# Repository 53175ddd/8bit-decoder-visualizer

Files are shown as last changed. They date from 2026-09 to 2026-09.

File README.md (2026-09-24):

# 8bit-decoder-visualizer

基板イメージ



動作イメージ（YouTube に飛びます）

youtube (https://www.youtube.com/watch?v=ziqk_MC2Dsg)

## 部品表

| 部品番号 | 部品名 | 個数 | リンク |
|:----|:----|----:|:----|
| C1 | 0.1uF 1608M | 1 | [113374](<https://akizukidenshi.com/catalog/g/g113374/>) |
| D1 ~ D8 | LED 5mm | 8 | [112605](<https://akizukidenshi.com/catalog/g/g112605/>) |
| D9 ~ D16 | 1N4148W SOD-123F | 8 | [g116985](<https://akizukidenshi.com/catalog/g/g116985/>) |
| R1 ~ R8 | 1kΩ 1608M | 8 | [130351](<https://akizukidenshi.com/catalog/g/g130351/>) |
| R9 ~ R12 | 10kΩ 1608M | 4 | [130355](<https://akizukidenshi.com/catalog/g/g130355/>) |
| SW1 ~ SW8 | SPDT トグルスイッチ | 8 | [100300](<https://akizukidenshi.com/catalog/g/g100300/>) |
| U1 ~ U6 | 7 セグメント LED モジュール | 6 | [110360](<https://akizukidenshi.com/catalog/g/g110360/>) |
| U7 | 74HC595 | 1 | [131760](<https://akizukidenshi.com/catalog/g/g131760/>) |
| U8 | Seeed XIAO | 1 | [117044](<https://akizukidenshi.com/catalog/g/g117044/>) |

---

<a href="https://github.com/53175ddd/8bit-decoder-visualizer">This work</a> is licensed under <a href="https://creativecommons.org/licenses/by-sa/4.0/">CC BY-SA 4.0</a></br>


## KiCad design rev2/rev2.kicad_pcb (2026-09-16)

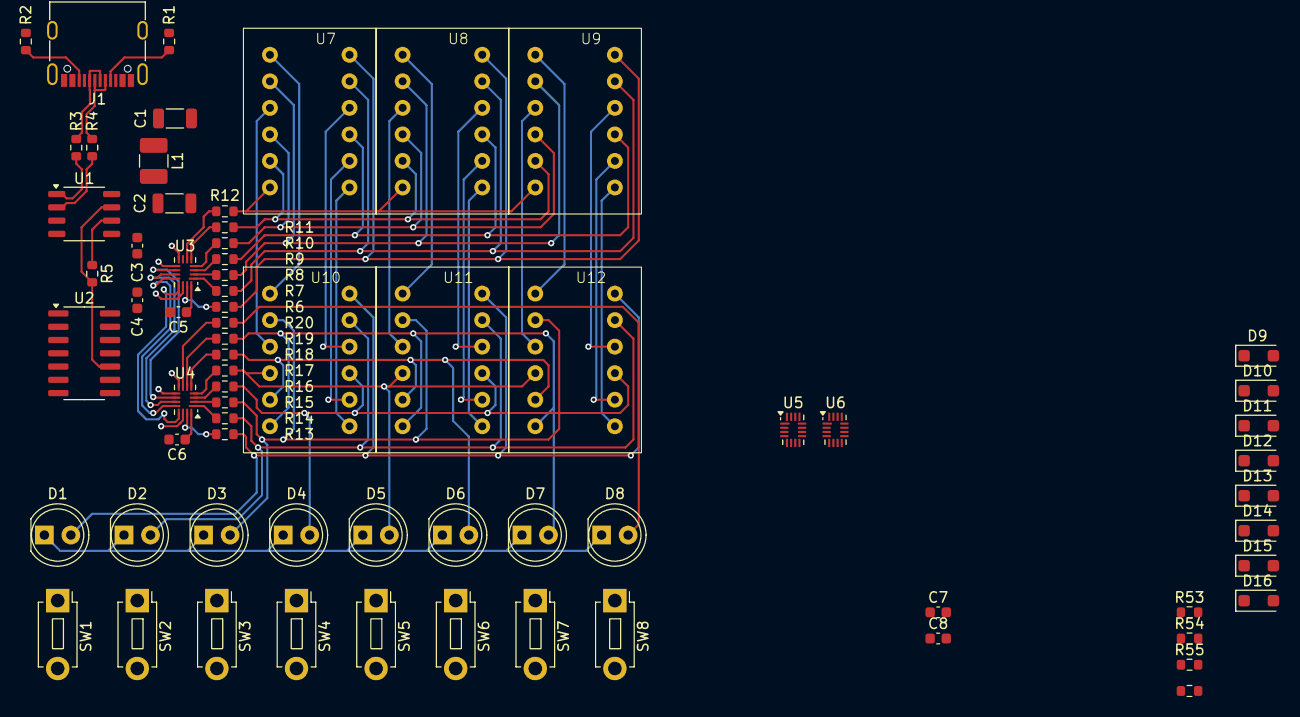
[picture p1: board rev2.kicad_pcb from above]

Board: 2 copper layers, 70 parts (0 on the bottom side), 78 nets.

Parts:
C1, C2: 10uF; L_1206_3216Metric
C3, C4, C5, C6, C7, C8: 0.1uF; C_0603_1608Metric
D1, D2, D3, D4, D5, D6, D7, D8: LED; LED_D5.0mm
D9, D10, D11, D12, D13, D14, D15, D16: D; D_SOD-123F
J1: USB_C_Receptacle_USB2.0_14P; USB_C_Receptacle_G-Switch_GT-USB-7010ASV
L1: 1.5uH; L_1210_3225Metric_Pad1.42x2.65mm_HandSolder
R1, R2: 5.1k; R_0603_1608Metric
R3, R4: 22; R_0603_1608Metric
R5, R6, R7, R8, R9, R10, R11, R12, R13, R14, R15, R16, R17, R18, R19, R20: 1k; R_0603_1608Metric
R53, R54, R55, R56: 10k; R_0603_1608Metric
SW1, SW2, SW3, SW4, SW5, SW6, SW7, SW8: SW_Push; SW_PUSH_1P1T_6x3.5mm_H4.3_APEM_MJTP1243
U1: CH340N; SOP-8_3.9x4.9mm_P1.27mm
U2: ATtiny1604-SS; SOIC-14_3.9x8.7mm_P1.27mm
U3, U4, U5, U6: 74HC595; UQFN-16_1.8x2.6mm_P0.4mm
U7, U8, U9, U10, U11, U12: C-2570SR

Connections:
+5V: C2.1, C3.1, C4.1, C5.1, C6.1, C7.1, C8.1, L1.2, R53.1, R54.1, R55.1, R56.1, U1.5 (VCC), U2.1 (VCC), U3.16 (VCC), U4.16 (VCC), U5.16 (VCC), U6.16 (VCC)
/DN: R4.2, U1.2 (UD-)
/DP: R3.2, U1.1 (UD+)
/HC595_CLEAR: U3.10 (~SRCLR), U4.10 (~SRCLR), U5.10 (~SRCLR), U6.10 (~SRCLR)
/HC595_CLOCK: U3.11 (SRCLK), U4.11 (SRCLK), U5.11 (SRCLK), U6.11 (SRCLK)
/HC595_EN: U3.13 (~OE), U4.13 (~OE), U5.13 (~OE), U6.13 (~OE)
/HC595_LATCH: U3.12 (RCLK), U4.12 (RCLK), U5.12 (RCLK), U6.12 (RCLK)
/READ_0: R53.2, SW1.2, SW5.2
/READ_1: R54.2, SW2.2, SW6.2
/READ_2: R55.2, SW3.2, SW7.2
/READ_3: R56.2, SW4.2, SW8.2
/SCAN_0: D9.1 (K), D10.1 (K), D11.1 (K), D12.1 (K)
/SCAN_1: D13.1 (K), D14.1 (K), D15.1 (K), D16.1 (K)
/SOURCE_1A: R6.2, U7.12 (ROW1), U8.12 (ROW1), U9.12 (ROW1)
/SOURCE_1B: R7.2, U7.11 (ROW2), U8.11 (ROW2), U9.11 (ROW2)
/SOURCE_1C: R8.2, U7.2 (ROW3), U8.2 (ROW3), U9.2 (ROW3)
/SOURCE_1D: R9.2, U7.9 (ROW4), U8.9 (ROW4), U9.9 (ROW4)
/SOURCE_1E: R10.2, U7.4 (ROW5), U8.4 (ROW5), U9.4 (ROW5)
/SOURCE_1F: R11.2, U7.5 (ROW6), U8.5 (ROW6), U9.5 (ROW6)
/SOURCE_1G: R12.2, U7.6 (ROW7), U8.6 (ROW7), U9.6 (ROW7)
/SOURCE_2A: D1.2 (A), R13.2, U10.12 (ROW1), U11.12 (ROW1), U12.12 (ROW1)
/SOURCE_2B: D2.2 (A), R14.2, U10.11 (ROW2), U11.11 (ROW2), U12.11 (ROW2)
/SOURCE_2C: D3.2 (A), R15.2, U10.2 (ROW3), U11.2 (ROW3), U12.2 (ROW3)
/SOURCE_2D: D4.2 (A), R16.2, U10.9 (ROW4), U11.9 (ROW4), U12.9 (ROW4)
/SOURCE_2E: D5.2 (A), R17.2, U10.4 (ROW5), U11.4 (ROW5), U12.4 (ROW5)
/SOURCE_2F: D6.2 (A), R18.2, U10.5 (ROW6), U11.5 (ROW6), U12.5 (ROW6)
/SOURCE_2G: D7.2 (A), R19.2, U10.6 (ROW7), U11.6 (ROW7), U12.6 (ROW7)
/SOURCE_2H: D8.2 (A), R20.2
/UPDI: R5.2, U1.7 (RXD), U2.10 (~RESET/PA0)
/USB_PLUG_DN: J1.A7 (D-), J1.B7 (D-), R4.1
/USB_PLUG_DP: J1.A6 (D+), J1.B6 (D+), R3.1
GND: C1.2, C2.2, C3.2, C4.2, C5.2, C6.2, C7.2, C8.2, J1.A1 (GND), J1.A12 (GND), J1.B1 (GND), J1.B12 (GND), J1.S1 (SHIELD), R1.2, R2.2, U1.3 (GND), U2.14 (GND), U3.8 (GND), U4.8 (GND), U5.8 (GND), U6.8 (GND)
unnamed: D1.1 (K), D2.1 (K), D3.1 (K), D4.1 (K), D5.1 (K), D6.1 (K), D7.1 (K), D8.1 (K)
unnamed: D9.2 (A), SW1.1
unnamed: D10.2 (A), SW2.1
unnamed: D11.2 (A), SW3.1
unnamed: D12.2 (A), SW4.1
unnamed: D13.2 (A), SW5.1
unnamed: D14.2 (A), SW6.1
unnamed: D15.2 (A), SW7.1
unnamed: D16.2 (A), SW8.1
unnamed: J1.A5 (CC1), R1.1
unnamed: J1.B5 (CC2), R2.1
unnamed: U7.1 (COL1), U10.1 (COL1)
unnamed: U7.3 (COL2), U10.3 (COL2)
unnamed: U7.10 (COL3), U10.10 (COL3)
unnamed: U7.7 (COL4), U10.7 (COL4)
unnamed: U7.8 (COL5), U10.8 (COL5)
unnamed: U8.1 (COL1), U11.1 (COL1)
unnamed: U8.3 (COL2), U11.3 (COL2)
unnamed: U8.10 (COL3), U11.10 (COL3)
unnamed: U8.7 (COL4), U11.7 (COL4)
unnamed: U8.8 (COL5), U11.8 (COL5)
unnamed: U9.1 (COL1), U12.1 (COL1)
unnamed: U9.3 (COL2), U12.3 (COL2)
unnamed: U9.10 (COL3), U12.10 (COL3)
unnamed: U9.7 (COL4), U12.7 (COL4)
unnamed: U9.8 (COL5), U12.8 (COL5)
unnamed: R5.1, U1.6 (TXD)
unnamed: R6.1, U3.15 (QA)
unnamed: R7.1, U3.1 (QB)
unnamed: R8.1, U3.2 (QC)
unnamed: R9.1, U3.3 (QD)
unnamed: R10.1, U3.4 (QE)
unnamed: R11.1, U3.5 (QF)
unnamed: R12.1, U3.6 (QG)
unnamed: U3.9 (QH'), U4.14 (SER)
unnamed: R13.1, U4.15 (QA)
unnamed: R14.1, U4.1 (QB)
unnamed: R15.1, U4.2 (QC)
unnamed: R16.1, U4.3 (QD)
unnamed: R17.1, U4.4 (QE)
unnamed: R18.1, U4.5 (QF)
unnamed: R19.1, U4.6 (QG)
unnamed: U4.9 (QH'), U5.14 (SER)
unnamed: R20.1, U4.7 (QH)
unnamed: U5.9 (QH'), U6.14 (SER)
VBUS: C1.1, J1.A4 (VBUS), J1.A9 (VBUS), J1.B4 (VBUS), J1.B9 (VBUS), L1.1

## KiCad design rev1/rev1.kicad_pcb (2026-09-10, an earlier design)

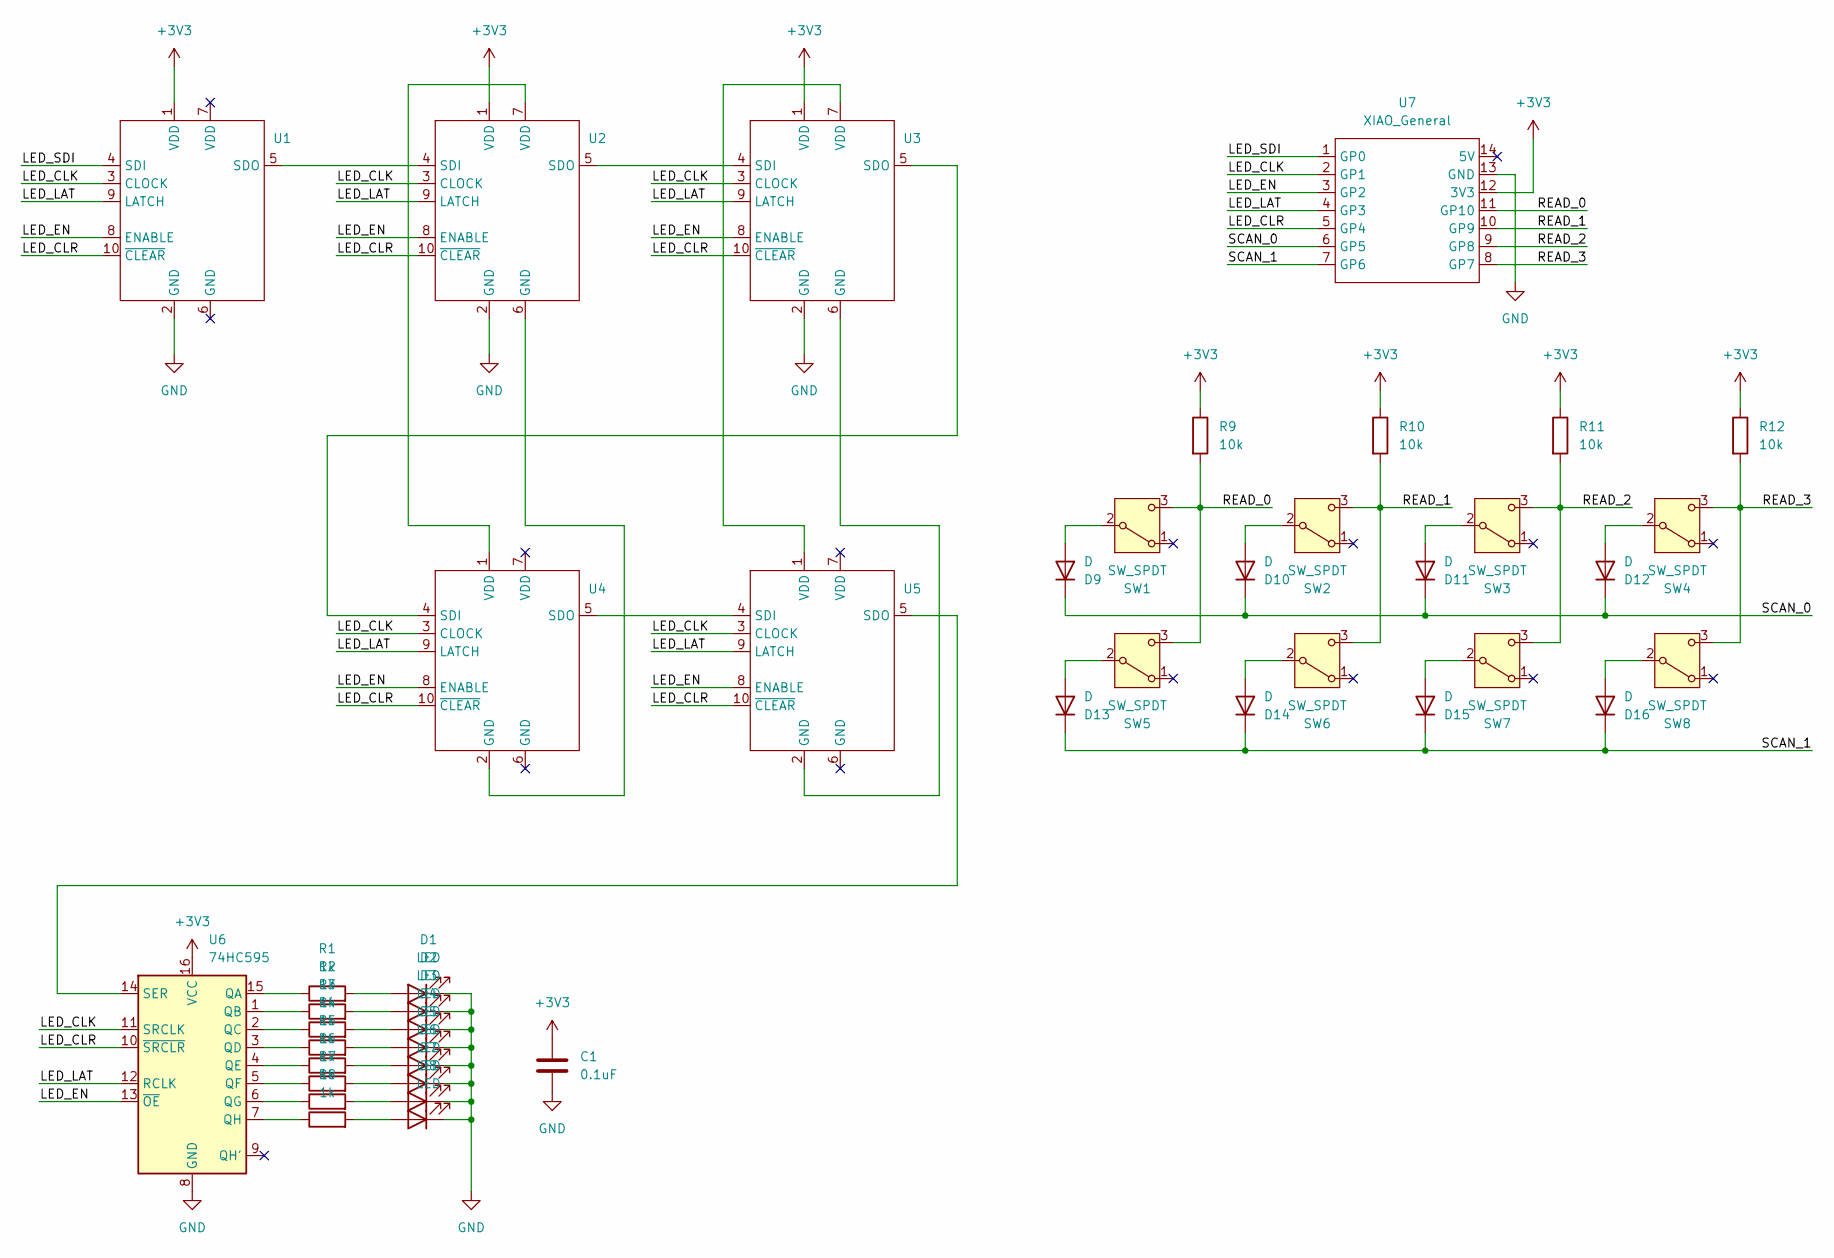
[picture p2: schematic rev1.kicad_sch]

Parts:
C1: 0.1uF; C_0603_1608Metric
D1, D2, D3, D4, D5, D6, D7, D8: LED; LED_D5.0mm
D9, D10, D11, D12, D13, D14, D15, D16: D; D_SOD-123F
R1, R2, R3, R4, R5, R6, R7, R8: 1k; R_0603_1608Metric
R9, R10, R11, R12: 10k; R_0603_1608Metric
SW1, SW2, SW3, SW4, SW5, SW6, SW7, SW8: SW_SPDT; SW_SPDT_100300
U1, U2, U3, U4, U5: LED Display Module; LED_Display_Module
U6: 74HC595; DIP-16_W7.62mm
U7: XIAO_General; XIAO_ESP32_C3

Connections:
+3V3: C1.1, R9.1, R10.1, R11.1, R12.1, U1.1 (VDD), U2.1 (VDD), U3.1 (VDD), U6.16 (VCC), U7.12 (3V3)
/LED_CLK: U1.3 (CLOCK), U2.3 (CLOCK), U3.3 (CLOCK), U4.3 (CLOCK), U5.3 (CLOCK), U6.11 (SRCLK), U7.2 (GP1)
/LED_CLR: U1.10 (~CLEAR), U2.10 (~CLEAR), U3.10 (~CLEAR), U4.10 (~CLEAR), U5.10 (~CLEAR), U6.10 (~SRCLR), U7.5 (GP4)
/LED_EN: U1.8 (ENABLE), U2.8 (ENABLE), U3.8 (ENABLE), U4.8 (ENABLE), U5.8 (ENABLE), U6.13 (~OE), U7.3 (GP2)
/LED_LAT: U1.9 (LATCH), U2.9 (LATCH), U3.9 (LATCH), U4.9 (LATCH), U5.9 (LATCH), U6.12 (RCLK), U7.4 (GP3)
/LED_SDI: U1.4 (SDI), U7.1 (GP0)
/READ_0: R9.2, SW1.3 (C), SW5.3 (C), U7.11 (GP10)
/READ_1: R10.2, SW2.3 (C), SW6.3 (C), U7.10 (GP9)
/READ_2: R11.2, SW3.3 (C), SW7.3 (C), U7.9 (GP8)
/READ_3: R12.2, SW4.3 (C), SW8.3 (C), U7.8 (GP7)
/SCAN_0: D9.1 (K), D10.1 (K), D11.1 (K), D12.1 (K), U7.6 (GP5)
/SCAN_1: D13.1 (K), D14.1 (K), D15.1 (K), D16.1 (K), U7.7 (GP6)
GND: C1.2, D1.1 (K), D2.1 (K), D3.1 (K), D4.1 (K), D5.1 (K), D6.1 (K), D7.1 (K), D8.1 (K), U1.2 (GND), U2.2 (GND), U3.2 (GND), U6.8 (GND), U7.13 (GND)
unnamed: D1.2 (A), R1.2
unnamed: D2.2 (A), R2.2
unnamed: D3.2 (A), R3.2
unnamed: D4.2 (A), R4.2
unnamed: D5.2 (A), R5.2
unnamed: D6.2 (A), R6.2
unnamed: D7.2 (A), R7.2
unnamed: D8.2 (A), R8.2
unnamed: D9.2 (A), SW1.2 (B)
unnamed: D10.2 (A), SW2.2 (B)
unnamed: D11.2 (A), SW3.2 (B)
unnamed: D12.2 (A), SW4.2 (B)
unnamed: D13.2 (A), SW5.2 (B)
unnamed: D14.2 (A), SW6.2 (B)
unnamed: D15.2 (A), SW7.2 (B)
unnamed: D16.2 (A), SW8.2 (B)
unnamed: U1.5 (SDO), U2.4 (SDI)
unnamed: U2.6 (GND), U4.2 (GND)
unnamed: U2.5 (SDO), U3.4 (SDI)
unnamed: U2.7 (VDD), U4.1 (VDD)
unnamed: U3.6 (GND), U5.2 (GND)
unnamed: U3.5 (SDO), U4.4 (SDI)
unnamed: U3.7 (VDD), U5.1 (VDD)
unnamed: U4.5 (SDO), U5.4 (SDI)
unnamed: U5.5 (SDO), U6.14 (SER)
unnamed: R1.1, U6.15 (QA)
unnamed: R2.1, U6.1 (QB)
unnamed: R3.1, U6.2 (QC)
unnamed: R4.1, U6.3 (QD)
unnamed: R5.1, U6.4 (QE)
unnamed: R6.1, U6.5 (QF)
unnamed: R7.1, U6.6 (QG)
unnamed: R8.1, U6.7 (QH)

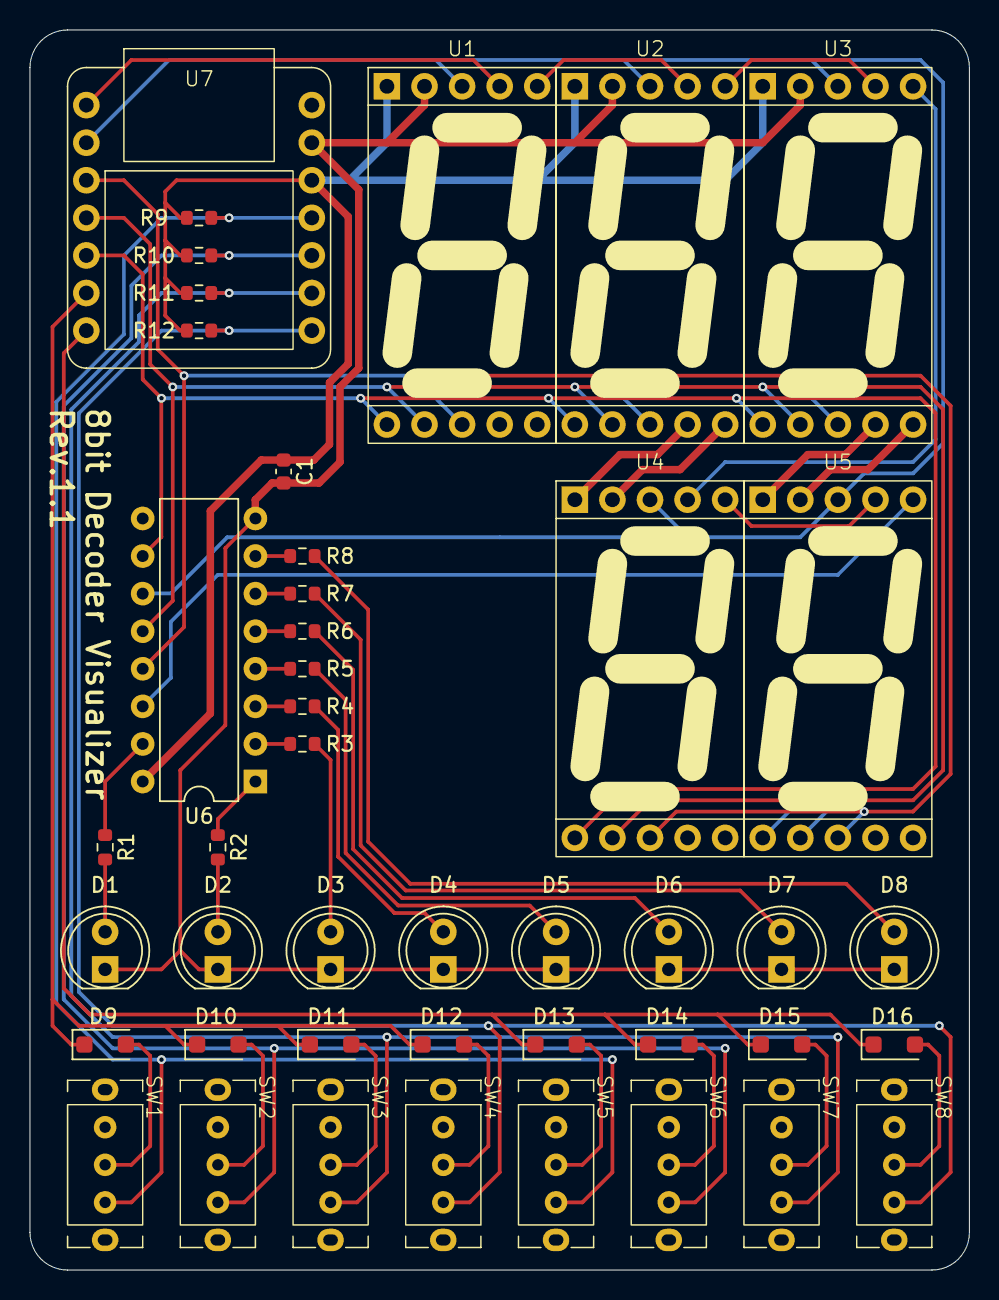
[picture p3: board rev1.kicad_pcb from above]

Board: 2 copper layers, 63.5 x 83.8 mm, 44 parts (0 on the bottom side), 46 nets.

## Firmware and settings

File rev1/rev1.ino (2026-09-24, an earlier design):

#define REV_1_1

#define LED_SDI  D0
#define LED_CLK  D1
#define LED_EN   D2
#define LED_LAT  D3
#define LED_CLR  D4
#define SCAN_0   D5
#define SCAN_1   D6
#define READ_0  D10
#define READ_1   D9
#define READ_2   D8
#define READ_3   D7

const uint8_t font[] = {0b11111100, 0b01100000, 0b11011010, 0b11110010, 0b01100110, 0b10110110, 0b10111110, 0b11100000, 0b11111110, 0b11110110, 0b11101110, 0b00111110, 0b00011010, 0b01111010, 0b10011110, 0b10001110};

const int8_t _scan[2] = {SCAN_0, SCAN_1};
const int8_t _read[4] = {READ_0, READ_1, READ_2, READ_3};


void init_io(void) {
  pinMode(LED_SDI, OUTPUT);
  pinMode(LED_CLK, OUTPUT);
  pinMode(LED_EN , OUTPUT);
  pinMode(LED_LAT, OUTPUT);
  pinMode(LED_CLR, OUTPUT);

  for(int8_t s = 0; s < 2; s++) {
    pinMode(_scan[s], OUTPUT);
    digitalWrite(_scan[s], HIGH);
  }

  for(int8_t r = 0; r < 4; r++) {
    pinMode(_read[r],  INPUT);
  }
}

void clear595(void) {
  digitalWrite(LED_CLR,  LOW);
  digitalWrite(LED_CLR, HIGH);
}

void send595(const uint8_t dat) {
  for(int8_t i = 0; i < 8; i++) {
    digitalWrite(LED_SDI, (dat >> i) & 1);
    digitalWrite(LED_CLK, HIGH);
    digitalWrite(LED_CLK, LOW);
  }
  digitalWrite(LED_SDI, LOW);
}

void latch595(void) {
  digitalWrite(LED_LAT, HIGH);
  digitalWrite(LED_LAT,  LOW);
}

uint8_t read_switch(void) {
  uint8_t res = 0;

  for(int8_t s = 0; s < 2; s++) digitalWrite(_scan[s], HIGH);

  for(int8_t s = 0; s < 2; s++) {
    digitalWrite(scan[s],  LOW);
    delayMicroseconds(20);

    for(int8_t r = 0; r < 4; r++) {
      res = (res << 1) + (digitalRead(_read[r]) == HIGH ? 0 : 1);
    }

    digitalWrite(_scan[s], HIGH);
  }

  return res;
}

void display(int8_t n) {
  static int8_t prev = -1;

  if(prev == n) return;
  prev = n;

#ifdef REV_1
  uint8_t vram[7] = {0};

  vram[0] = n;

  vram[6] = vram[0] / 100;
  vram[5] = (vram[0] / 10) % 10;
  vram[4] = vram[0] % 10;
  vram[3] = 0;
  vram[2] = vram[0] >> 4;
  vram[1] = vram[0] & 0x0F;

  vram[6] = font[vram[6]];
  vram[5] = font[vram[5]];
  vram[4] = font[vram[4]];
  vram[2] = font[vram[2]];
  vram[1] = font[vram[1]];

  if(vram[6] == font[0]) {
    vram[6] = 0;
    if(vram[5] == font[0]) {
      vram[5] = 0;
    }
  }

  if(vram[2] == font[0]) {
    vram[2] = 0;
  }
#endif

#ifdef REV_1_1
  uint8_t vram[6] = {0};

  vram[0] = n;

  vram[5] = vram[0] / 100;
  vram[4] = (vram[0] / 10) % 10;
  vram[3] = vram[0] % 10;
  vram[2] = vram[0] >> 4;
  vram[1] = vram[0] & 0x0F;

  vram[5] = font[vram[5]];
  vram[4] = font[vram[4]];
  vram[3] = font[vram[3]];
  vram[2] = font[vram[2]];
  vram[1] = font[vram[1]];

  if(vram[5] == font[0]) {
    vram[5] = 0;
    if(vram[4] == font[0]) {
      vram[4] = 0;
    }
  }

  if(vram[2] == font[0]) {
    vram[2] = 0;
  }
#endif

  for(int8_t i = 0; i < sizeof(vram); i++) {
    send595(vram[i]);
  }
  latch595();
}

void setup() {
  init_io();
  clear595();
}

void loop() {
  uint8_t n = read_switch();
  display(n);

  delay(25);
}

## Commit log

2026-08-18 kicad pj
    [8bit-decoder-visualizer.kicad_pcb, 8bit-decoder-visualizer.kicad_sch]
2026-08-18 デフォルトフットプリント割り当て
2026-08-18 表示器部分の回路作成
    [8bit-decoder-visualizer.kicad_sch]
2026-08-18 xiao のシンボル
2026-08-18 xiao の fp
2026-08-18 xiao との接続以外の回路を書いた
    [8bit-decoder-visualizer.kicad_sch]
2026-08-18 フットプリントの割り当てを忘れてたでヤンス
    [8bit-decoder-visualizer.kicad_sch]
2026-08-18 sym fp リメイク
2026-08-18 大まかな配線引いた
    [8bit-decoder-visualizer.kicad_pcb]
2026-08-18 未確定の配線を割り当て
    [8bit-decoder-visualizer.kicad_sch]
2026-08-18 配線整理
    [8bit-decoder-visualizer.kicad_pcb]
2026-08-18 回路調整
    [8bit-decoder-visualizer.kicad_sch]
2026-08-18 fix AW
    [8bit-decoder-visualizer.kicad_pcb]
2026-08-18 基板外形と寸法線
    [8bit-decoder-visualizer.kicad_pcb]
2026-08-18 シルク追加
    [8bit-decoder-visualizer.kicad_pcb]
2026-08-18 配線手直し
    [8bit-decoder-visualizer.kicad_pcb]
2026-08-18 基板外形をラウンドに変更
    [8bit-decoder-visualizer.kicad_pcb]
2026-08-19 配置配線を調整して基板を小型化
    [8bit-decoder-visualizer.kicad_pcb]
2026-09-02 ガーバー出力
    [8bit-decoder-visualizer.kicad_pcb]
2026-09-02 部品表作った
    [8bit-decoder-visualizer.kicad_sch]
2026-09-10 あるべきフットプリント
2026-09-10 いらない LED を消してスイッチのフットプリントを修正し、Rev.2 とする
    [8bit-decoder-visualizer.kicad_pcb, 8bit-decoder-visualizer.kicad_sch]
2026-09-10 基板中央とページ中央に近いグリッドがズレているのが気になったので平行移動
    [8bit-decoder-visualizer.kicad_pcb]
2026-09-10 Rev.2 じゃなくて Rev.1.1 にした
    [8bit-decoder-visualizer.kicad_pcb]
2026-09-10 replace to sub dir
    [8bit-decoder-visualizer.kicad_pcb, 8bit-decoder-visualizer.kicad_sch]
2026-09-10 create new version
    [rev2.kicad_pcb, rev2.kicad_sch]
2026-09-10 LED のシンボル作った
2026-09-10 LED のフットプリント
2026-09-11 だいたいの回路図書いた
    [rev2.kicad_sch]
2026-09-11 直前に表示した値と同じ値が渡されたら表示の更新をスキップするようにした
2026-09-13 ドットマトリックスを追加してダイナミック点灯に変更
    [rev2.kicad_sch]
2026-09-13 dot matrix のフットプリント
2026-09-13 再アノテーション
    [rev2.kicad_sch]
2026-09-13 作ったフットプリントを割り当て
    [rev2.kicad_sch]
2026-09-13 完全に作り直すので、一旦削除
    [rev2.kicad_pcb, rev2.kicad_sch]
2026-09-13 プロジェクト作成
    [rev2.kicad_pcb, rev2.kicad_sch]
2026-09-13 大まかな回路図描いた
    [rev2.kicad_sch]
2026-09-16 aw がんばった
    [rev2.kicad_pcb, rev2.kicad_sch]
2026-09-16 表示器セグメントのシンク回路を単純化した
    [rev2.kicad_sch]
2026-09-16 回路図で消した部品を削除
    [rev2.kicad_pcb]
2026-09-24 sw マトリクスの制御部分の配列化と for 文化
2026-09-26 add connection
    [rev2.kicad_sch]

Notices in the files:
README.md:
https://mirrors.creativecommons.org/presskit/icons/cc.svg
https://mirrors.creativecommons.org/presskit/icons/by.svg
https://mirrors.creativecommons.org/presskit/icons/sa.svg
